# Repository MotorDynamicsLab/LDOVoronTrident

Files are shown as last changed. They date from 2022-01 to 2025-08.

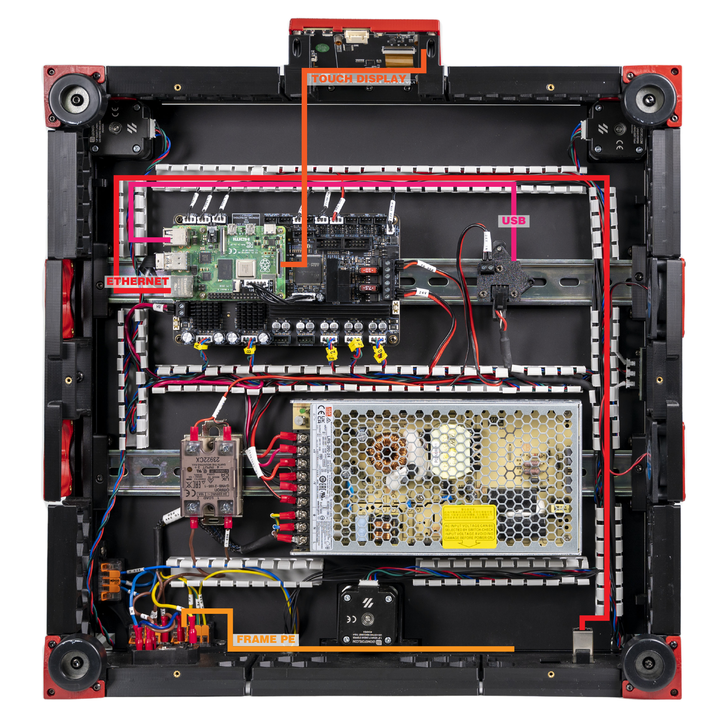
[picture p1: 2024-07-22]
Images/WiringGuide/RevD/08_mapping.jpg

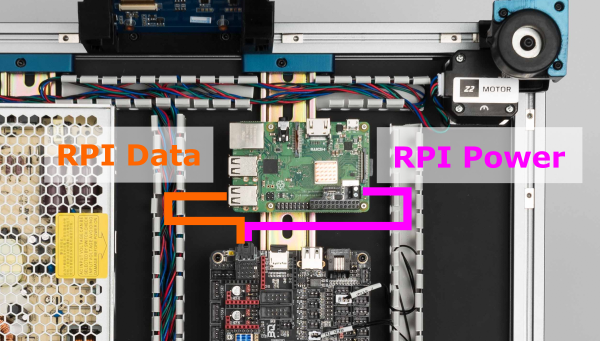
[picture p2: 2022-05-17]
Images/WiringGuide/s08_mapping.png

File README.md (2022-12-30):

# LDO Voron Trident Kit
This repository contains supplementary information/configuration/3d models for the LDO Voron Trident Kit

We would thank the Voron Design team for all of their hard work and contributions to the 3D printing community.

This repo contains both original and derivative works from the Voron project, 
which is licensed GPLv3. This repo therefore is also licensed under the terms 
of the GNU Public License, verison 3.

GPLv3 License Attributions:

https://github.com/VoronDesign/Voron-Trident
https://github.com/VoronDesign/Voron-2
https://github.com/VoronDesign/Voron-Stealthburner

For more information and support:

https://vorondesign.com

https://discord.gg/voron

https://docs.ldomotors.com

https://www.ldomotion.com

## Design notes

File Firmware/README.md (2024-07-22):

# LDO Voron Trident Configs

## octopus-printer-rev-a.cfg

This contains mainboard configs for LDO Trident kits Rev.A

## octopus-printer-rev-c.cfg

This contains mainboard configs for LDO Trident kits Rev.C. Changes include:

- Change chamber thermistor type to ATC Semitec 104NT, kit now uses externally mounted thermistor

## printer-leviathan-rev-d.cfg

This contains mainboard configs for LDO Trident kits Rev.D

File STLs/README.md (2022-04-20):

## Power Inlet 1.2mm
This part replaces the `power_inlet_adamstech` part from the official [Voron repo](https://github.com/VoronDesign/Voron-Trident/blob/main/STLs/Skirt/power_inlet_adamstech.stl). This part adapts specifically to 1.2mm AC inlets for a better fit.

## LDO Z Cable Anchor
The LDO deck panel has a Z cable opening that is in a slightly different position than the original. Use this part to match the anchor with the new opening.  

## LDO Deck Wire Cover Right
The LDO deck panel has a larger rear right opening. This part will cover the larger opening more completely. 

## Bed WAGO Mount
This part holds the 2x2 WAGO terminals as well as a 2x2 JST XH Splicing PCB for the build plate.

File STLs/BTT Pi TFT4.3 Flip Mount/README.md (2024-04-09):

## Touchscreen Flip Mount for BigTreeTech Pi TFT4.3
This is a remix based on the [Waveshare 4.3 touchscreen mount](https://github.com/VoronDesign/VoronUsers/tree/master/printer_mods/jeoje/4.3_Inch_Touchscreen_Mount/STL/2.4) by jeoje. 

This mount does NOT require rotating the scree via the configuration, however the brightness buttons are not accesible with the normal mount.  The thick mount will allow access with a pointy device.

Print the faceplate in the accent colour of your choice. The mount uses M3 brass heatset inserts and M3x8(or M3x10) screws to fasten the faceplate on each side. 
Use the screws provided in the BTT touchscreen packaging to fasten the screen to the mount.

### Fastener Count  
- 4 M2.5x6 (included with BTT screen)
- 5 M3x8 
- 3 M3 roll-in nut
- 2 M3 heatset insert

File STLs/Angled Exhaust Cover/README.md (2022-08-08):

## Angled Exhaust Cover
This mod tilts the entry angle of the reverse bowden tube, so that there is minimal interference with the back of the toolhead while it moves around at max Y. 

### Fastener Count:  
- 4 M3x8  
- 4 M3 heatsink insert  
- 2 M5x10  
- 2 M5 roll-in nut

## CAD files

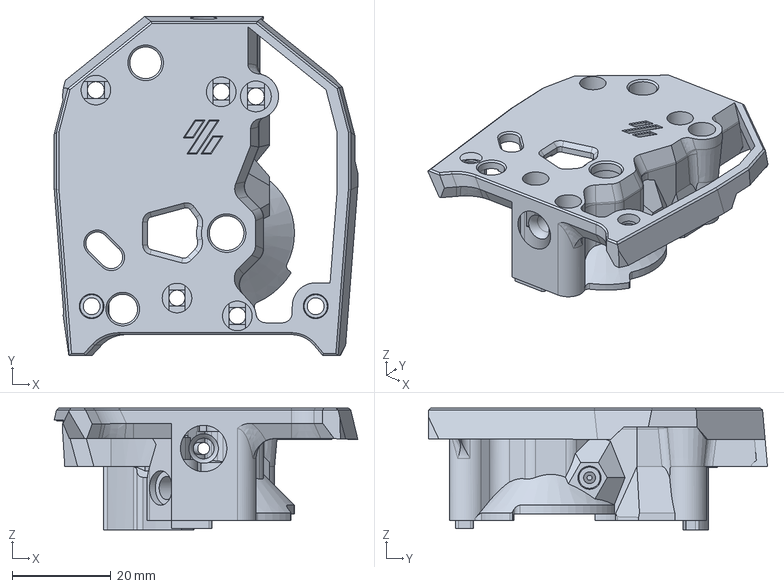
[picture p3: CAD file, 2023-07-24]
STLs/LDOSBCW2MountCover/main_body.step
61.5 x 68.7 x 24.7 mm
LDO AB PCB Assembly

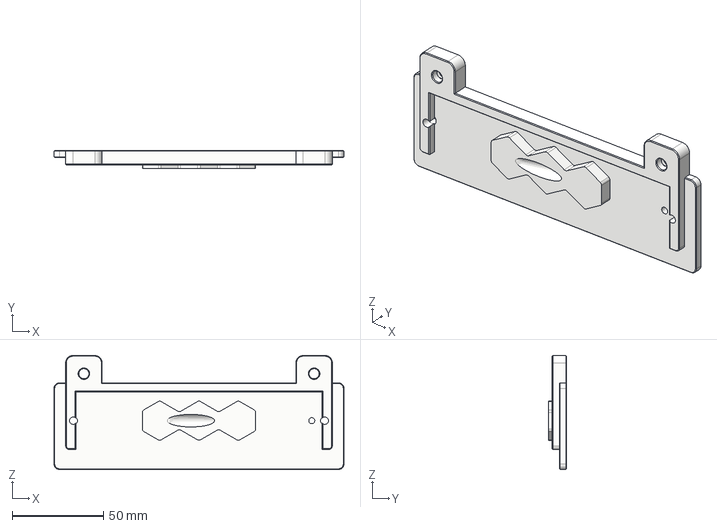
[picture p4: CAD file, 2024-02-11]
STLs/Angled Exhaust Cover/exhaust_cover.step
159.2 x 10.0 x 62.6 mm

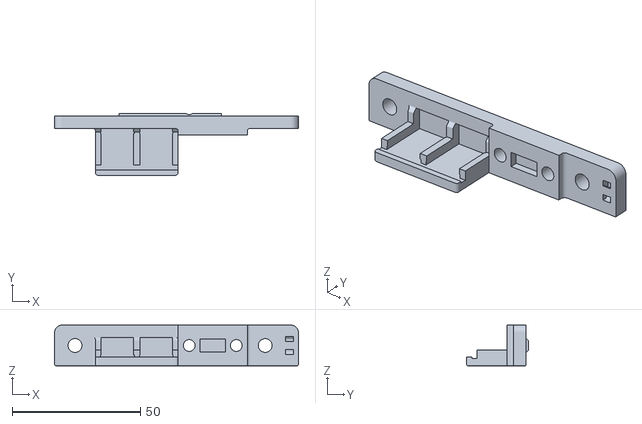
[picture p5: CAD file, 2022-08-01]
STLs/bed_wago_mount.stl
95.3 x 24.0 x 16.0

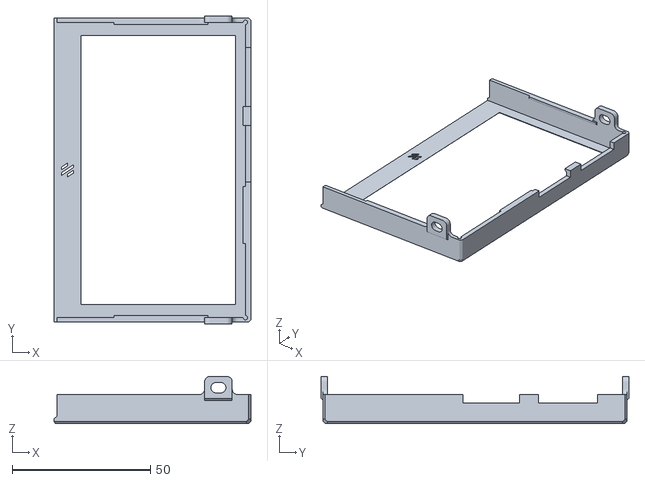
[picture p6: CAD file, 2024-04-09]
STLs/BTT Pi TFT4.3 Flip Mount/[a]_faceplate.stl
71.2 x 111.4 x 17.1

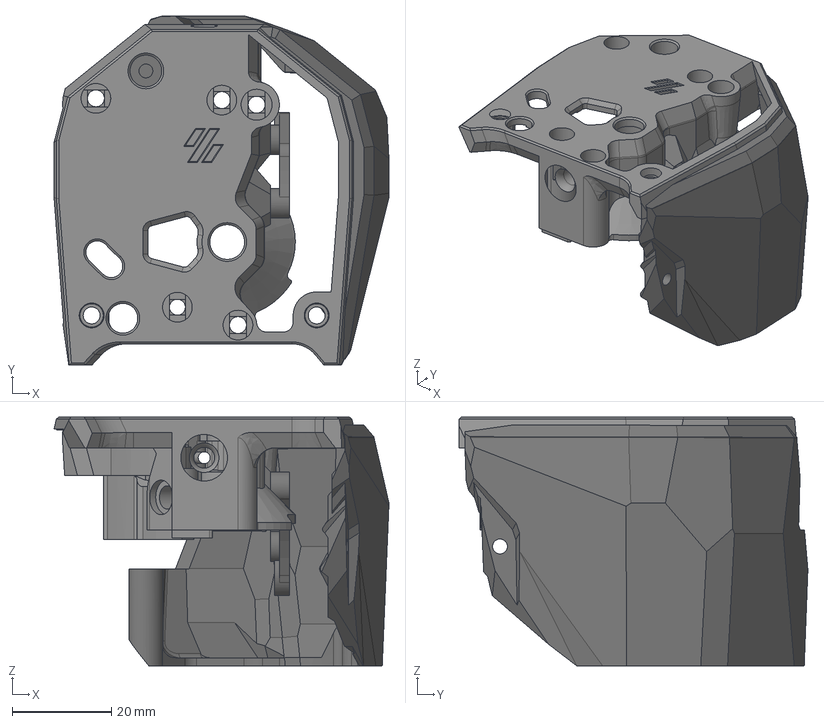
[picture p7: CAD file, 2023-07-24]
STLs/LDOSBCW2MountCover/Stealthburner_CW2_LDOPCB.step
67.6 x 70.4 x 50.2 mm
pcb_spacer v2 v9
cable_cover_for_pcb v9
main_body

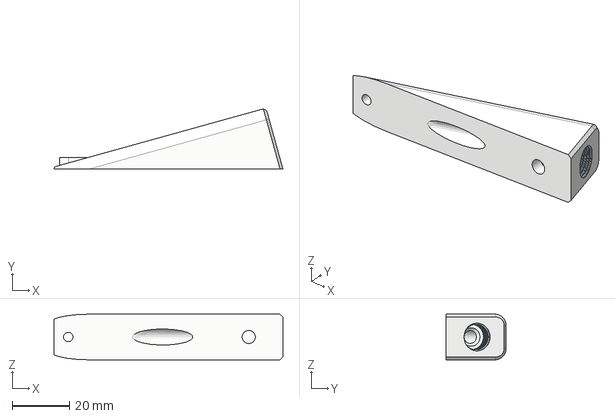
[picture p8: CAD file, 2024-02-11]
STLs/Angled Exhaust Cover/coupler_mount.step
80.2 x 21.1 x 16.0 mm

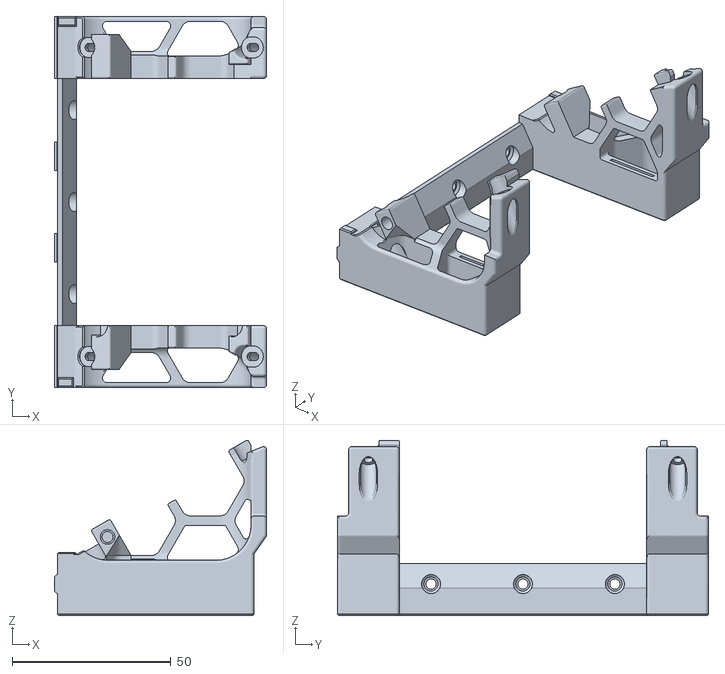
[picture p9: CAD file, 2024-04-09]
STLs/BTT Pi TFT4.3 Flip Mount/mount_thick.stl
67.0 x 117.0 x 55.3

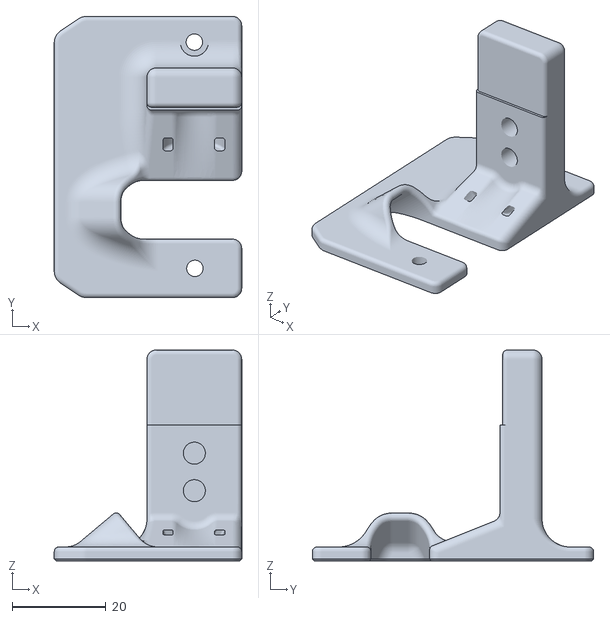
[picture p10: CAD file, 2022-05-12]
STLs/ldo_z_cable_anchor.stl
40.0 x 60.0 x 45.0

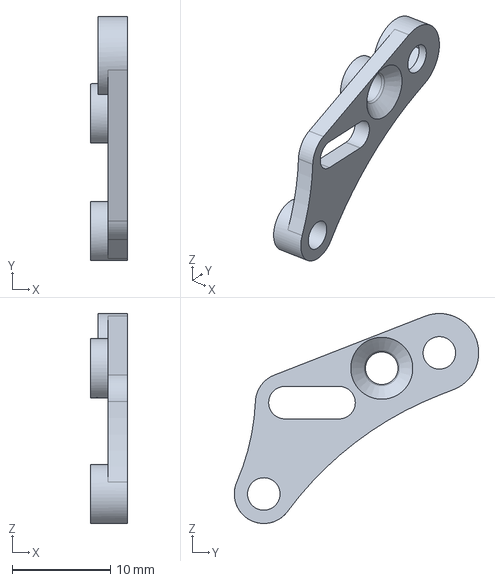
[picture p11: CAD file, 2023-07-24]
STLs/LDOSBCW2MountCover/pcb_spacer.step
3.80 x 24.8 x 21.3 mm

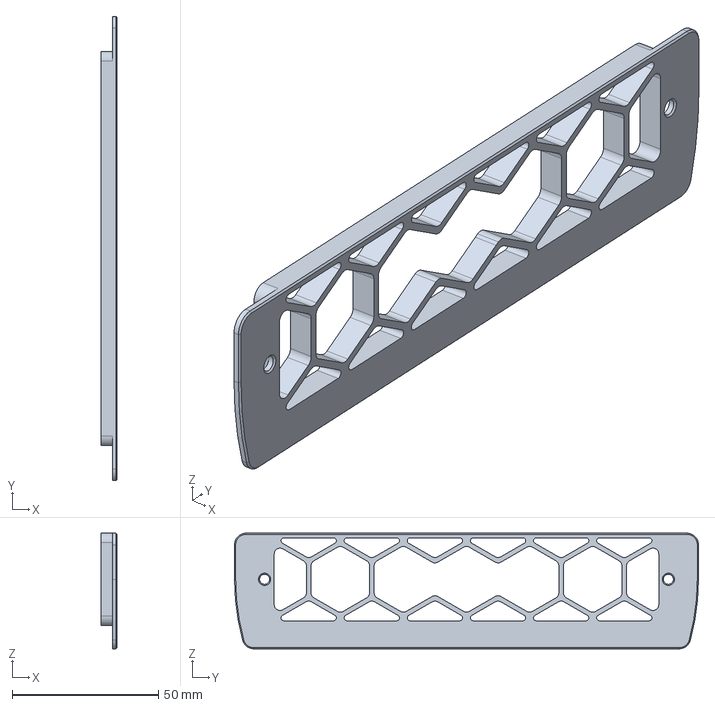
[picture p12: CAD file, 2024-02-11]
STLs/Angled Exhaust Cover/exhaust_grill.step
5.60 x 158.8 x 39.6 mm

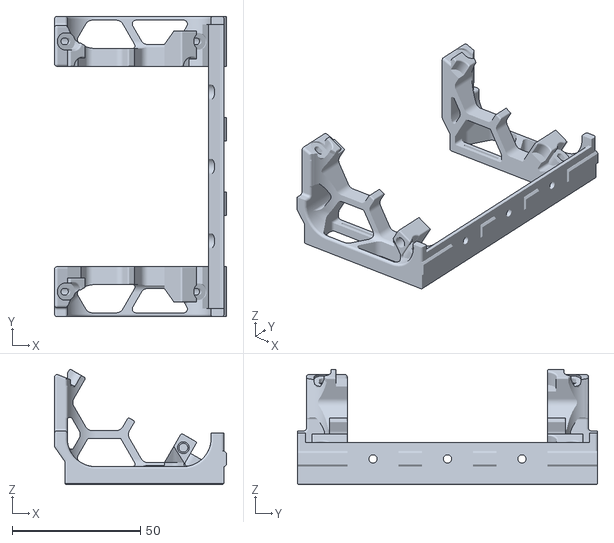
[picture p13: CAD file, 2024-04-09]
STLs/BTT Pi TFT4.3 Flip Mount/mount.stl
67.0 x 117.0 x 44.8

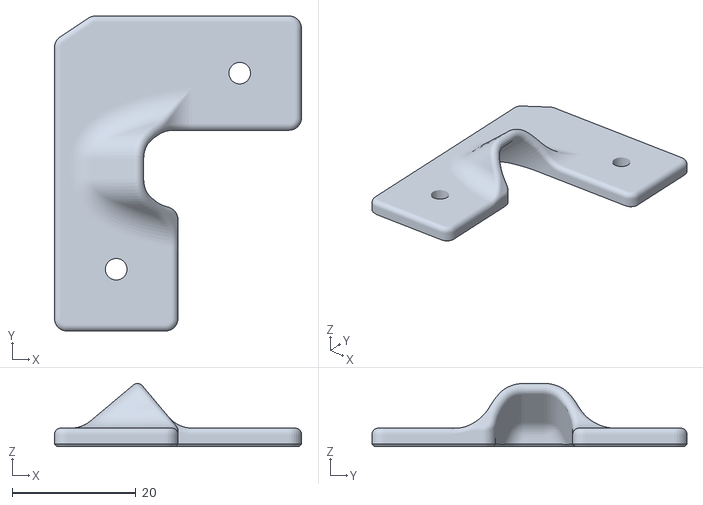
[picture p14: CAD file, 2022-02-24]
STLs/ldo_deck_wire_cover_right.stl
40.0 x 51.0 x 10.2

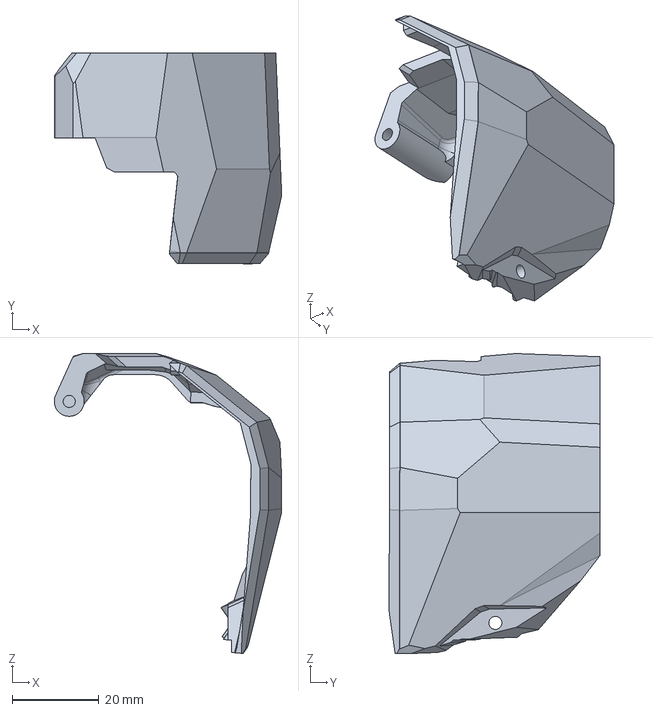
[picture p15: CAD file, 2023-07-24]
STLs/LDOSBCW2MountCover/cable_cover_for_pcb.step
52.5 x 48.6 x 69.2 mm

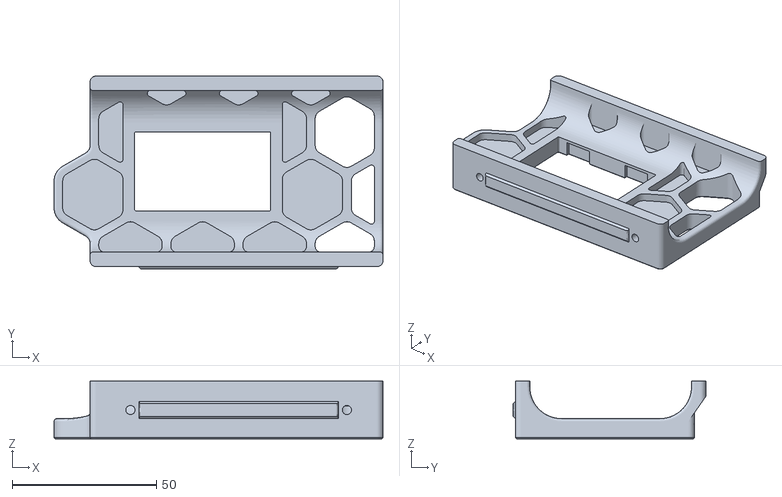
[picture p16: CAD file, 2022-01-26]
STLs/power_inlet_1.2mm.stl
114.0 x 66.8 x 20.0

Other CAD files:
STLs/LDOSBCW2MountCover/LDOSBCW2Mount.step
STLs/LDOSBCW2MountCover/LDOSBCW2MountCover.3mf
STLs/LDOSBCW2MountCover/LDOSBCW2Cover.step
STLs/BTT Pi TFT4.3 Mount/mount_thick.stl
STLs/Angled Exhaust Cover/Exhaust Cover Angled.f3d
STLs/Angled Exhaust Cover/coupler_mount.stl
STLs/Angled Exhaust Cover/exhaust_cover.stl
STLs/Angled Exhaust Cover/exhaust_grill.stl
STLs/BTT Pi TFT4.3 Mount/BTT Pi TFT4.3 Mount.f3d
STLs/BTT Pi TFT4.3 Mount/[a]_faceplate.stl
STLs/BTT Pi TFT4.3 Mount/mount.stl
STLs/Bed WAGO Mount.f3d
STLs/LDO Deck Wire Cover Right.f3d
STLs/LDO Z Cable Anchor.f3d
STLs/LDOSBCW2MountCover/LDOSBCW2Cover.stl
STLs/LDOSBCW2MountCover/LDOSBCW2Mount.stl
STLs/LDOSBCW2MountCover/Stealthburner_CW2_LDOPCB.3mf
STLs/LDOSBCW2MountCover/cable_cover_for_pcb.stl
STLs/LDOSBCW2MountCover/deprecated/LDOSBCW2Cover.step
STLs/LDOSBCW2MountCover/deprecated/LDOSBCW2Cover.stl
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

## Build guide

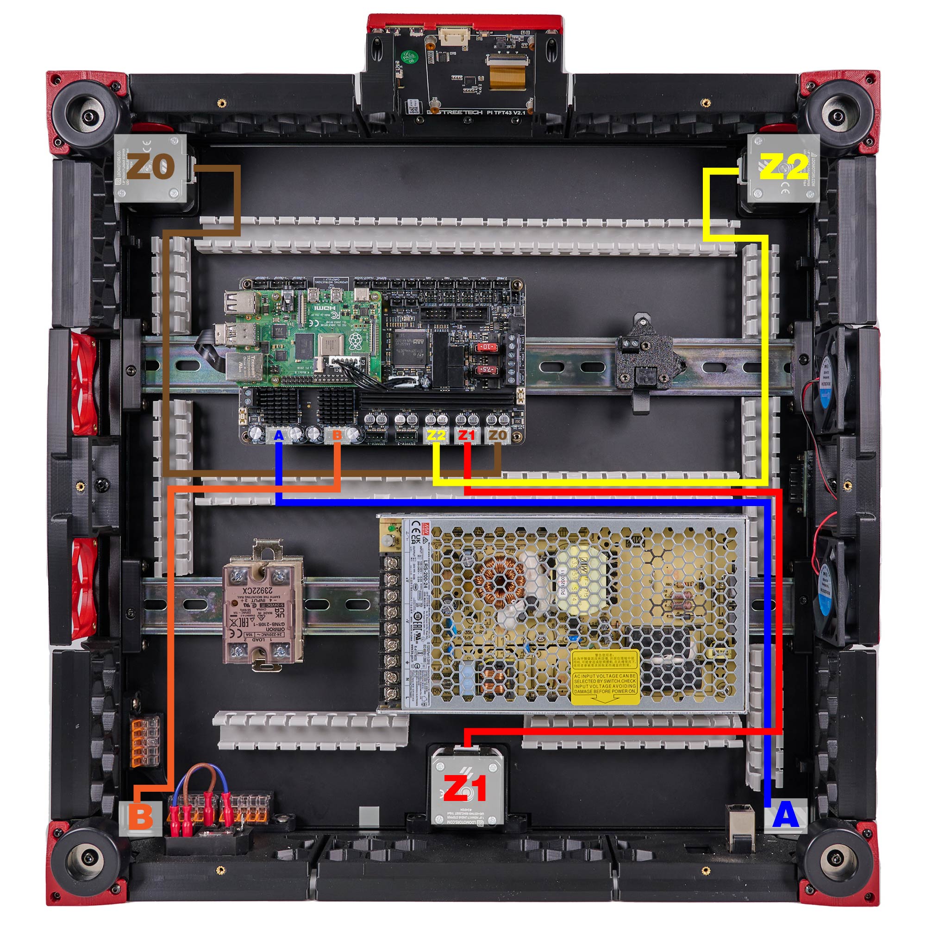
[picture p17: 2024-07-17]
Images/WiringGuide/RevD/01_mapping.jpg

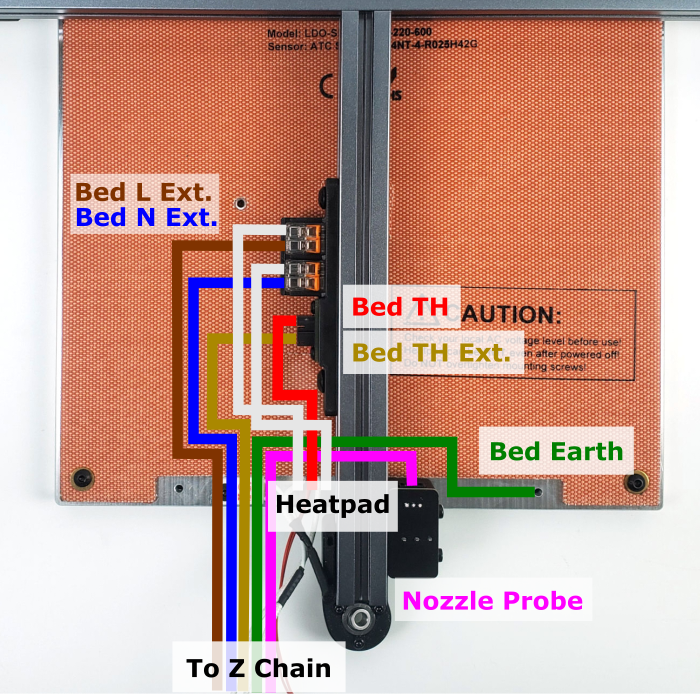
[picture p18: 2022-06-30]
Images/WiringGuide/build_plate_mapping.png

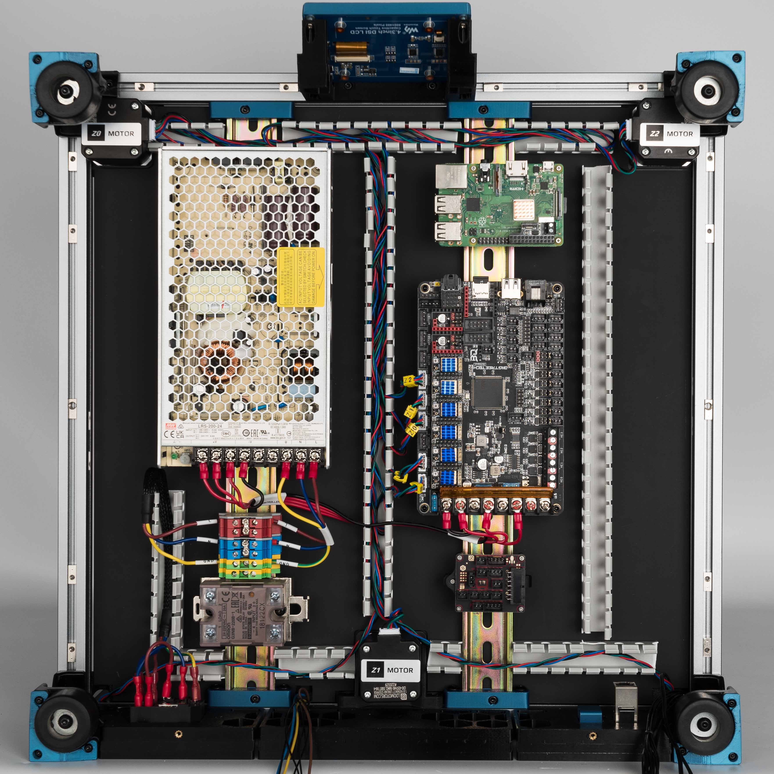
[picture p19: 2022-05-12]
Images/WiringGuide/s06_controller_pwr.jpg

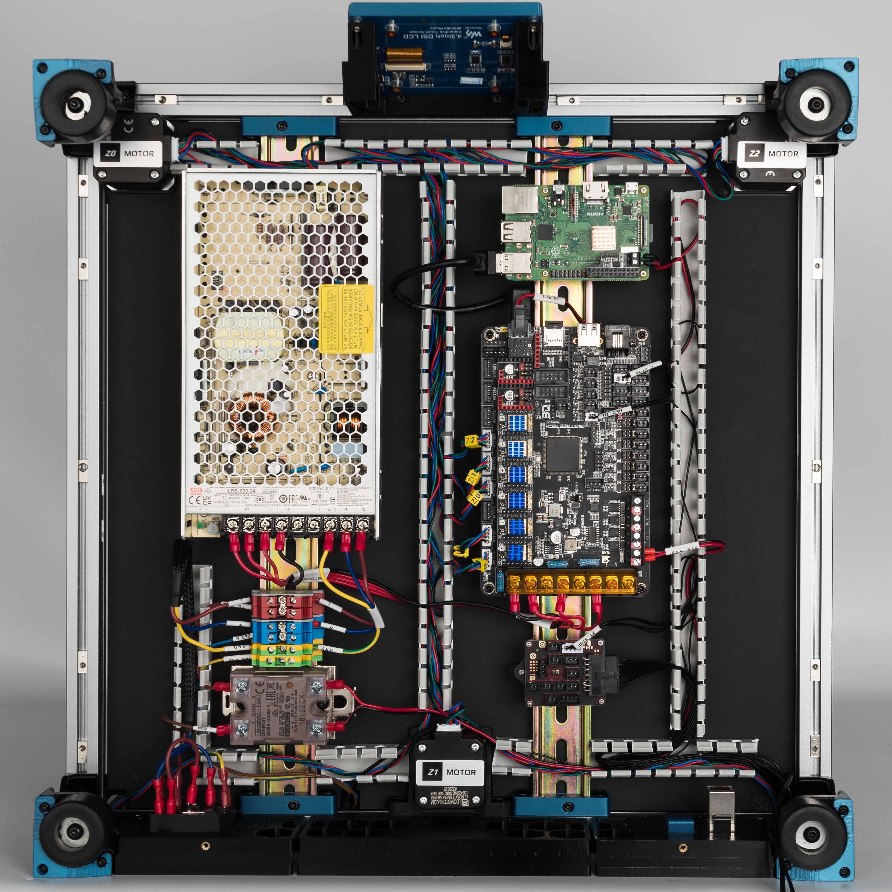
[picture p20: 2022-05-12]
Images/WiringGuide/s09_toolhead.jpg

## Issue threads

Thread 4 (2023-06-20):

STLs/ldo_deck_wire_cover_right.stl is identical to the original Voron Trident's part

maxim-kukushkin, 2023-06-20:
This file (referenced in the LDO's Assembly Guide) is actually identical to the original part of Voron Trident. I.e., the opening is the same size and doesn't fit the Toolhead cable. It's also clear when mounting it to the printer, as the cut in the panel is much wider than the whole in the printed part

camerony, 2024-02-04:
added comment to printed part docs

Closed 2024-02-04.

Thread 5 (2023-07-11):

Config for LDO Trident Missing pullup_resistor config

ehrenhasz, 2023-07-11:
When using the LOD config at defaults for the hotend sensor type the hotend thermistor reports 3x higher than ambient temperature.

Adding the following to the extruder section allowed for the hotend extruder to report the correct temp.

pullup_resistor: 5000

camerony, 2024-02-04:
No Issue found.

Closed 2024-08-06.

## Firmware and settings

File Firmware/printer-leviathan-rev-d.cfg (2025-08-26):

# This file contains common pin mappings for the LDO Voron 2.4 Rev. D kit
# See docs/Config_Reference.md for a description of parameters.

# See docs/Config_Reference.md for a description of parameters.

## Voron Design VORON Trident 250/300/350mm Leviathan V1.1 config

## *** THINGS TO CHANGE/CHECK: ***
## MCU paths                            [mcu] section
## Thermistor types                     [extruder] and [heater_bed] sections - See https://www.klipper3d.org/Config_Reference.html#common-thermistors for common thermistor types
## Z Endstop Switch location            [safe_z_home] section
## Homing end position                  [gcode_macro G32] section
## Z Endstop Switch  offset for Z0      [stepper_z] section
## Probe points                         [quad_gantry_level] section
## Min & Max gantry corner postions     [quad_gantry_level] section
## PID tune                             [extruder] and [heater_bed] sections
## Probe pin                            [probe] section
## Fine tune E steps                    [extruder] section

[mcu]
##  Obtain definition by "ls -l /dev/serial/by-id/" then unplug to verify
##--------------------------------------------------------------------
serial: /dev/serial/by-id/{REPLACE WITH YOUR SERIAL}
restart_method: command
##--------------------------------------------------------------------

[mcu nhk]
##  Obtain definition by "ls -l /dev/serial/by-id/" then unplug to verify
##--------------------------------------------------------------------
serial: /dev/serial/by-id/{REPLACE WITH YOUR SERIAL}
restart_method: command
##--------------------------------------------------------------------

[printer]
kinematics: corexy
max_velocity: 300  
max_accel: 10000
max_z_velocity: 15          #Max 15 for 12V TMC Drivers, can increase for 24V
max_z_accel: 350
square_corner_velocity: 5.0

#####################################################################
#   X/Y Stepper Settings
#####################################################################

##  B Stepper - Left
##  Connected to HV STEPPER 0
##  Endstop connected to X-ENDSTOP
[stepper_x]
step_pin: PB10
dir_pin: !PB11
enable_pin: !PG0
rotation_distance: 40
microsteps: 32
full_steps_per_rotation:400  #set to 200 for 1.8 degree stepper
endstop_pin: PC1
position_min: 0
##--------------------------------------------------------------------

##  Uncomment below for 250mm build
#position_endstop: 250
#position_max: 250

##  Uncomment for 300mm build
#position_endstop: 300
#position_max: 300

##  Uncomment for 350mm build
#position_endstop: 350
#position_max: 350

##--------------------------------------------------------------------
homing_speed: 25   #Max 100
homing_retract_dist: 5
homing_positive_dir: true

##  Make sure to update below for your relevant driver (2209 or 5160)
[tmc5160 stepper_x]
cs_pin: PE15
spi_bus: spi4
#diag0_pin: ^!PG1
interpolate: false
run_current: 0.8
sense_resistor: 0.075
stealthchop_threshold: 0

##  A Stepper - Right
##  Connected to HV STEPPER 1
##  Endstop connected to Y-ENDSTOP
[stepper_y]
step_pin: PF15
dir_pin: !PF14
enable_pin: !PE9
rotation_distance: 40
microsteps: 32
full_steps_per_rotation:400  #set to 200 for 1.8 degree stepper
endstop_pin: PC2
position_min: 0
##--------------------------------------------------------------------

##  Uncomment for 250mm build
#position_endstop: 250
#position_max: 250

##  Uncomment for 300mm build
#position_endstop: 300
#position_max: 300

##  Uncomment for 350mm build
#position_endstop: 350
#position_max: 350

##--------------------------------------------------------------------
homing_speed: 25  #Max 100
homing_retract_dist: 5
homing_positive_dir: true

##  Make sure to update below for your relevant driver (2209 or 5160)
[tmc5160 stepper_y]
cs_pin: PE11
spi_bus: spi4
#diag0_pin: ^!PE10
interpolate: false
run_current: 0.8
sense_resistor: 0.075
stealthchop_threshold: 0
 
#####################################################################
#   Z Stepper Settings
#####################################################################

## Z0 Stepper - Front Left
##  Connected to STEPPER 0
##  Endstop connected to Z-ENDSTOP
[stepper_z]
step_pin: PD4
dir_pin: PD3
enable_pin: !PD7
# Rotation Distance for TR8x8 = 8, TR8x4 = 4, TR8x2 = 2
rotation_distance: 4 
microsteps: 32
endstop_pin: PC3
##  Z-position of nozzle (in mm) to z-endstop trigger point relative to print surface (Z0)
##  (+) value = endstop above Z0, (-) value = endstop below
##  Increasing position_endstop brings nozzle closer to the bed
##  After you run Z_ENDSTOP_CALIBRATE, position_endstop will be stored at the very end of your config
position_endstop: -0.5
##--------------------------------------------------------------------

##  Uncomment below for 250mm build
#position_max: 230

##  Uncomment below for 300mm build
#position_max: 280

##  Uncomment below for 350mm build
#position_max: 330

##--------------------------------------------------------------------
position_min: -5
homing_speed: 8
second_homing_speed: 3
homing_retract_dist: 3

##  Make sure to update below for your relevant driver (2209 or 5160)
[tmc2209 stepper_z]
uart_pin: PD5
#diag_pin: ^!PD6
interpolate: false
run_current: 0.8
sense_resistor: 0.110
stealthchop_threshold: 0

##  Z1 Stepper - Rear Center
##  Connected to STEPPER 1
[stepper_z1]
step_pin: PC12
dir_pin: PC11
enable_pin: !PD2
# Rotation Distance for TR8x8 = 8, TR8x4 = 4, TR8x2 = 2
rotation_distance: 4 
microsteps: 32

##  Make sure to update below for your relevant driver (2209 or 5160)
[tmc2209 stepper_z1]
uart_pin: PD0
#diag_pin: ^!PD1
interpolate: false
run_current: 0.8
sense_resistor: 0.110
stealthchop_threshold: 0

##  Z2 Stepper - Front Right
##  Connected to STEPPER 2
[stepper_z2]
step_pin: PC9
dir_pin: PC8
enable_pin: !PC10
# Rotation Distance for TR8x8 = 8, TR8x4 = 4, TR8x2 = 2
rotation_distance: 4 
microsteps: 32

##  Make sure to update below for your relevant driver (2209 or 5160)
[tmc2209 stepper_z2]
uart_pin: PA8
#diag_pin: ^!PA15
interpolate: false
run_current: 0.8
sense_resistor: 0.110
stealthchop_threshold: 0

#####################################################################
#   Extruder
#####################################################################

##  Connected to STEPPER 0
##  Heater - HEATER
##  Thermistor - TH0
[extruder]
step_pin: nhk:gpio23
dir_pin: nhk:gpio24
enable_pin: !nhk:gpio25
##  Update value below when you perform extruder calibration
##  If you ask for 100mm of filament, but in reality it is 98mm:
##  rotation_distance = <previous_rotation_distance> * <actual_extrude_distance> / 100
##  22.6789511 is a good starting point
rotation_distance: 22.6789511   #Bondtech 5mm Drive Gears
##  Update Gear Ratio depending on your Extruder Type
##  Use 50:10 for Stealthburner/Clockwork 2
##  Use 50:17 for Afterburner/Clockwork (BMG Gear Ratio)
##  Use 80:20 for M4, M3.1
gear_ratio: 50:10               #BMG Gear Ratio
microsteps: 32
full_steps_per_rotation: 200    #200 for 1.8 degree, 400 for 0.9 degree
nozzle_diameter: 0.400
filament_diameter: 1.75
heater_pin: nhk:gpio9
## Check what thermistor type you have. See https://www.klipper3d.org/Config_Reference.html#common-thermistors for common thermistor types.
## Use "Generic 3950" for NTC 100k 3950 thermistors
sensor_type: ATC Semitec 104NT-4-R025H42G
sensor_pin: nhk:gpio29
pullup_resistor: 2200
min_temp: 10
max_temp: 270
max_power: 1.0
min_extrude_temp: 170
control = pid
pid_kp = 26.213
pid_ki = 1.304
pid_kd = 131.721
##  Try to keep pressure_advance below 1.0
#pressure_advance: 0.05
##  Default is 0.040, leave stock
#pressure_advance_smooth_time: 0.040

##  E0 on MOTOR6
##  Connected to STEPPER 4
[tmc2209 extruder]
uart_pin: nhk:gpio0
tx_pin: nhk:gpio1
interpolate: false
run_current: 0.5
sense_resistor: 0.100
stealthchop_threshold: 0


#####################################################################
#   Bed Heater
#####################################################################

[heater_bed]
##  SSR Pin - HEATBED
##  Thermistor - TH1
heater_pin: PG11
## Check what thermistor type you have. See https://www.klipper3d.org/Config_Reference.html#common-thermistors for common thermistor types.
## Use "Generic 3950" for Keenovo heaters
sensor_type: ATC Semitec 104NT-4-R025H42G
sensor_pin: PA2
pullup_resistor: 2200
##  Adjust Max Power so your heater doesn't warp your bed. Rule of thumb is 0.4 watts / cm^2 .
max_power: 0.6
min_temp: 0
max_temp: 120
control: pid
pid_kp: 58.437
pid_ki: 2.347
pid_kd: 363.769

#####################################################################
#   Probe
#####################################################################

[probe]
##  Inductive Probe
##  Connected to Z-PROBE
##  This probe is not used for Z height, only Quad Gantry Leveling
pin: nhk:gpio10
x_offset: 0
y_offset: 25.0
z_offset: 0
speed: 10.0
samples: 3
samples_result: median
sample_retract_dist: 3.0
samples_tolerance: 0.006
samples_tolerance_retries: 3
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

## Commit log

2022-01-26 add 1.2mm power inlet
    [Power Inlet 1.2mm.f3d, power_inlet_1.2mm.stl]
2022-02-24 add LDO Deck Wire Cover Right and LDO Z Cable Anchor
    [LDO Deck Wire Cover Right.f3d, LDO Z Cable Anchor.f3d, ldo_deck_wire_cover_right.stl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]
2022-02-24 fix incorrect orientation of ldo_deck_wire_cover_right.stl
    [ldo_deck_wire_cover_right.stl]
2022-04-20 add Bed WAGO Mount
    [Bed WAGO Mount.f3d, bed_wago_mount.stl]
2022-04-26 add preliminary wiring guide photos
2022-05-05 remove counterbore in Bed WAGO Mount to prevent M5x10 screws from bottoming out on the extrusion
    [Bed WAGO Mount.f3d, bed_wago_mount.stl]
2022-05-12 Updated LDO kit specific Z cable chain anchor.
    [LDO Z Cable Anchor.f3d, ldo_z_cable_anchor.stl]
2022-05-12 update new wiring guide photos, previous set had wrong polarity at SSR connection
2022-05-12 increase exposure of wire guide photos slightly
2022-05-13 add step 3 mapping as well as rail_close_up.png
2022-05-16 add step 4-5 wiring diagrams
2022-05-17 add step 7 wiring diagram
2022-05-17 add step 8/10/12 wiring diagrams
2022-05-17 add step 14 wiring diagram
2022-05-17 add touch display ribbon cable connection photos to add with orientation
2022-05-17 add detailed photo of raspberry pi power connection
2022-05-27 modify the thermistor PCB mounting holes in bed_wago_mount to accept longer screws than M3x6
    [Bed WAGO Mount.f3d, bed_wago_mount.stl]
2022-06-08 add klipper config that works with the wiring guide
    [printer-octopus.cfg]
2022-06-15 fix a number of issues & mistakes in printer-octopus.cfg
    [printer-octopus.cfg]
2022-06-17 add build plate wiring photos
2022-06-28 add wiring photos of trident 250
2022-06-28 add final high resolution wiring photo for trident 250
2022-06-28 add photos showing 3x2 XH splicer PCB positioning and a photo showing frame grounding positioning
2022-06-29 add led strip routing diagram
2022-06-30 add frame grounding point and wiring route to s05_mapping
2022-06-30 rename GND to earth in s05_mapping
2022-08-01 mirror Bed WAGO Mount to match orientation in wiring guide
    [Bed WAGO Mount.f3d, bed_wago_mount.stl]
2022-08-01 add BTT Pi TFT4.3 Mount
    [BTT Pi TFT4.3 Mount.f3d, [a]_faceplate.stl, mount.stl]
2022-08-01 update STLs/BTT Pi TFT4.3 Mount/README.md with fastener description
2022-08-08 update BTT Pi TFT4.3 Mount/[a]_faceplate.stl with beefier screw tabs
    [BTT Pi TFT4.3 Mount.f3d, [a]_faceplate.stl]
2022-08-08 Add Angled Exhaust Cover
    [Exhaust Cover Angled.f3d, coupler_mount.stl, exhaust_cover.stl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]
2022-08-08 add fastener count to BTT Pi TFT4.3 Mount/README.md
2022-08-09 change the default thermistor settings to 104NT, change the default Z max to 240 and update comments
    [printer-octopus.cfg]
2022-08-22 SB +CW2 Mount and Cover
    [LDOSBCW2Cover.step, LDOSBCW2Cover.stl, LDOSBCW2Mount.step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]
2023-03-17 add printer-octopus-rev-c.cfg and README to document changes to config
    [printer-octopus-rev-c.cfg]
2023-05-05 update faceplate for BTT PiTFT43 to be compatible with V2.1
    [[a]_faceplate.stl]
2023-06-25 fix orientation of the faceplate
    [[a]_faceplate.stl]
2023-07-24 Update motor_body to match new Voron update
    [LDOSBCW2Cover.step, LDOSBCW2Cover.stl, LDOSBCW2Mount.step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]
2023-08-17 Remove scale for caselight
    [printer-octopus-rev-a.cfg, printer-octopus-rev-c.cfg]
2024-02-11 Updated Resolution & Step
    [coupler_mount.step, coupler_mount.stl, exhaust_cover.step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]
2024-04-09 Added flip mount for screen
    Does not require rotating the screen configuration
    [[a]_faceplate.stl, mount.stl, mount_thick.stl]
2024-07-17 update RevD wiring images
2024-07-18 correct the polarity indication in the image for the USB Adapter PCB
2024-07-22 add cfg file for rev d and update readme
    [printer-leviathan-rev-d.cfg]
2024-07-23 fix mistakes in pin assignments and title block in printer-leviathan-rev-d.cfg
    [printer-leviathan-rev-d.cfg]
2024-07-30 revise the routing for LED wire
2024-09-23 fix th configure
    [printer-leviathan-rev-d.cfg]
2024-09-23 fix the config for thermistor
    [printer-leviathan-rev-d.cfg]
2024-11-19 fix extruder sense_resistor
    [printer-leviathan-rev-d.cfg]
2024-12-06 Update PRINT_START
    [printer-leviathan-rev-d.cfg, printer-octopus-rev-c.cfg]
2025-08-26 disable sweeping in `resonance_tester` section
    [printer-leviathan-rev-d.cfg]
